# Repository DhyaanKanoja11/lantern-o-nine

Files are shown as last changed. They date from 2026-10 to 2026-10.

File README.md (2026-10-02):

# **Lantern-o-Nine**

A 9-key custom macropad built around the Seeed XIAO RP2040, featuring an EC11 rotary encoder for volume control, a 0.91" OLED display to show current status, and SK6812 RGB underglow. Housed in a custom 3D printed snap-fit case with a honeycomb vent rosette and debossed name!

Made as a submission to [Hack Club's Hackpad](https://hackpad.hackclub.com/) program.  
> *This is my first hardware project! Thank you Hack Club for this amazing opportunity!! <3*

---

<p align="center">
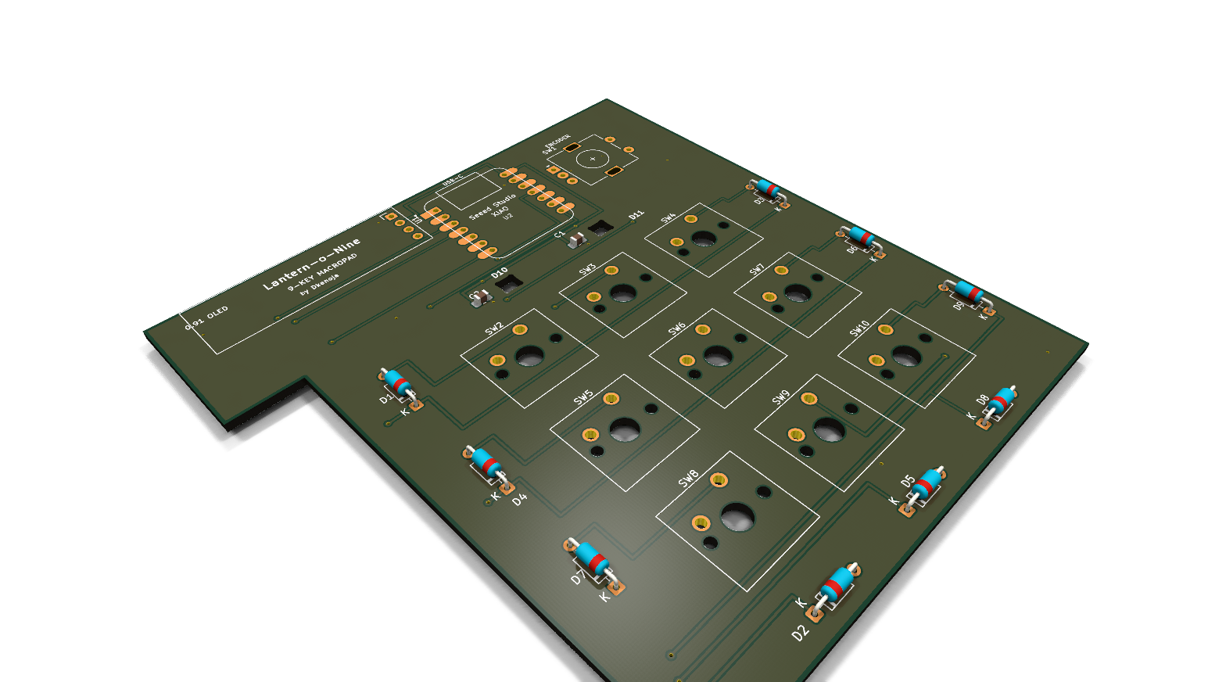
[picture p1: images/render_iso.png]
Lantern-o-Nine 3D Render
  
</p>

### Quick Links
- [View CAD Files](./CAD/)
- [View PCB Files](./PCB/)
- [View Firmware](./Firmware/)
- [View Production Files](./production/)

---

## Pictures & Design Files

### 3D PCB Renders
| Top View | Bottom View |
| :---: | :---: |
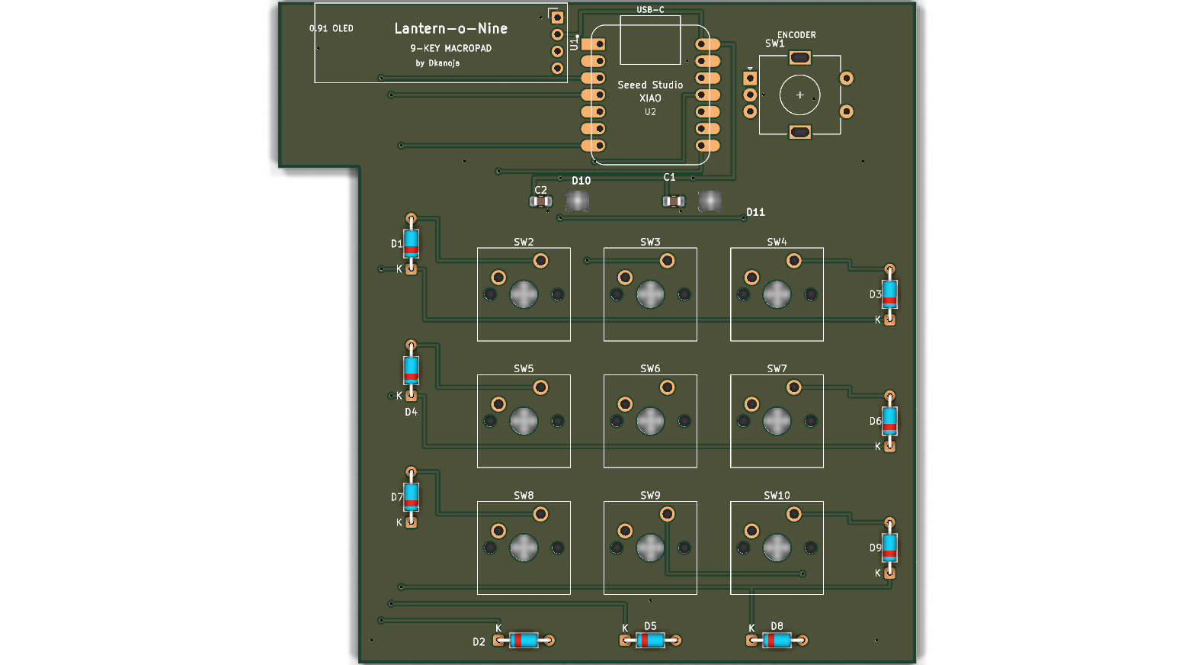
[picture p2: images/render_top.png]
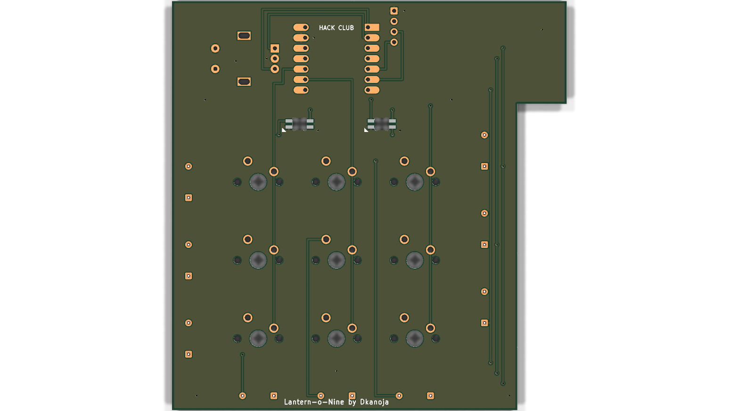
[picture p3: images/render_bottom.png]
|  |  |

### Schematic & PCB Routing
| Schematic Diagram | 2D PCB Layout |
| :---: | :---: |
|  |  |

### 3D CAD Enclosure & Mechanical Assembly
| Exploded Assembly (PCB Encasing) | Fully Assembled Case | Bottom Case (Rosette & Logo) |
| :---: | :---: | :---: |
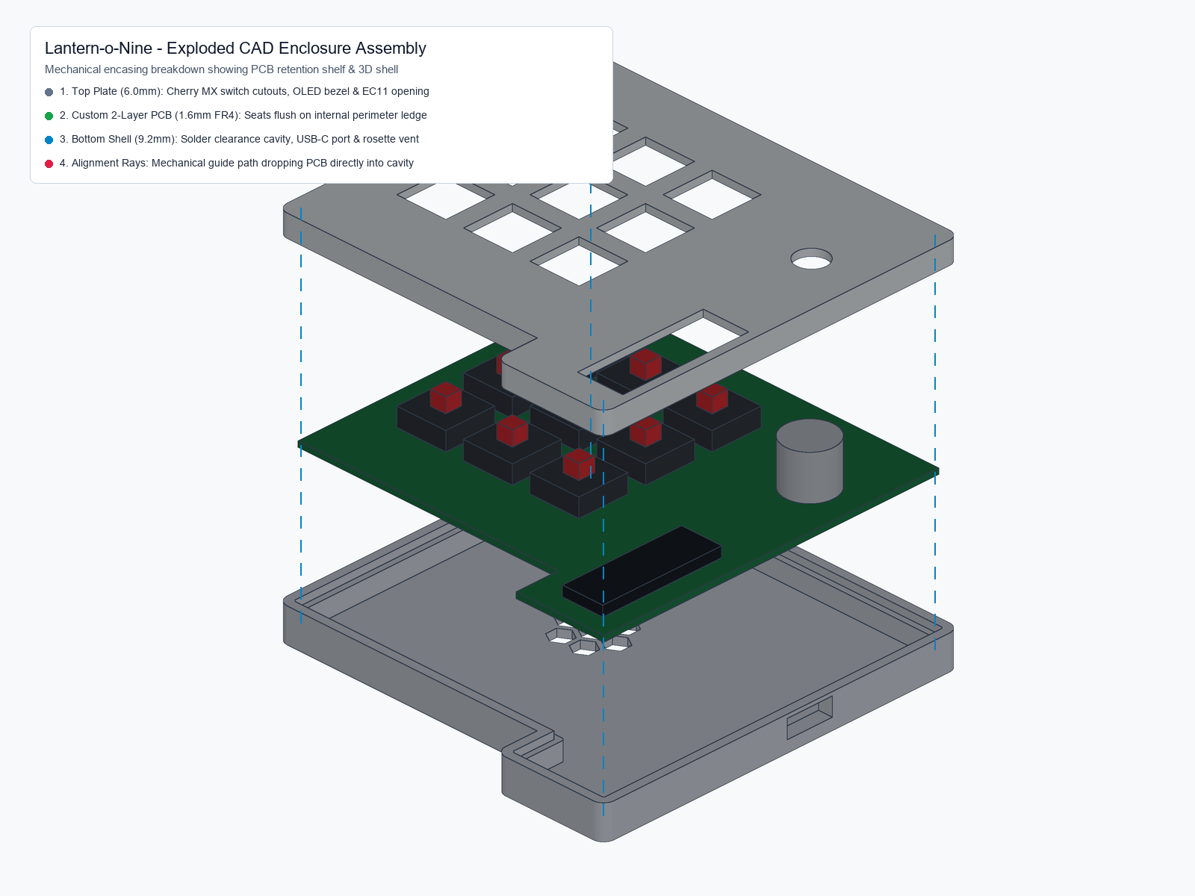
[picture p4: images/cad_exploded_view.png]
Exploded Assembly View
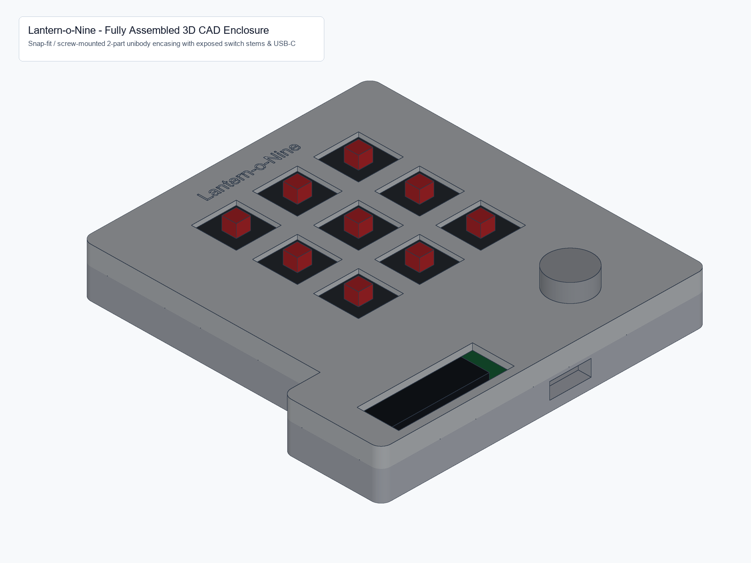
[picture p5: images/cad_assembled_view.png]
Fully Assembled CAD View
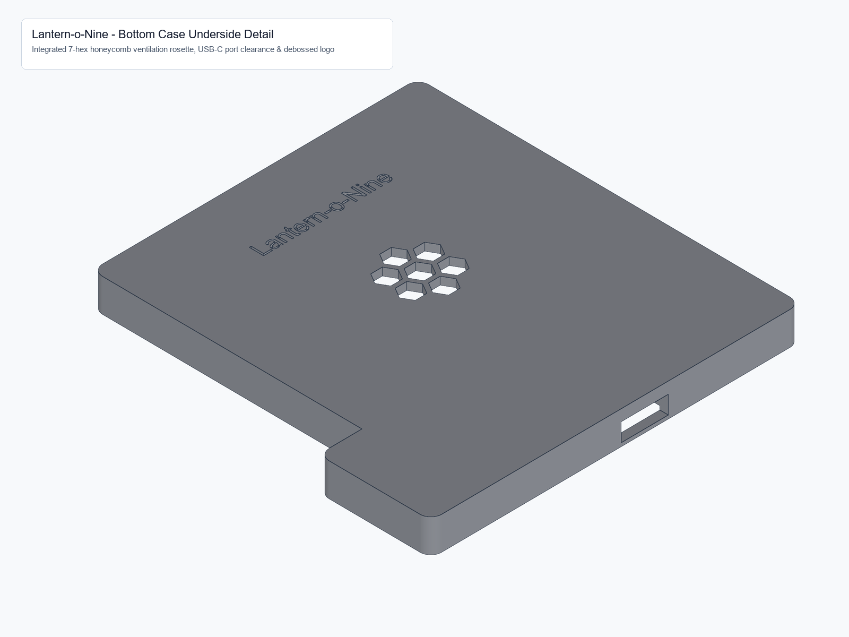
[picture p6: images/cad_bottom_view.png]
Bottom Case Detail View
|  |  |  |

The 2-piece enclosure consists of a 6.0mm top plate and 9.2mm bottom shell:
- **Mechanical Encasing:** The custom 2-layer PCB (1.6mm FR4) drops directly into the bottom shell, seating flush on an internal perimeter retention shelf with dedicated clearance below for diode and switch pin solder joints.
- **Top Plate Retention:** The top plate caps the assembly, clamping the PCB securely while exposing the 9 Cherry MX switch stems through 14x14mm cutouts, an OLED viewing bezel, and a rotary encoder shaft opening.
- **Thermal & Ports:** The underside features an integrated 7-hex honeycomb ventilation rosette and debossed "Lantern-o-Nine" branding, with an aligned rear cutout for the Seeed Xiao USB-C port.

---

## Features
- **9 Cherry MX Mechanical Switches** in a 3x3 matrix with 1N4148 diodes so there's zero ghosting (NKRO).
- **EC11 Rotary Encoder** to smoothly change volume up/down, plus click-to-mute.
- **0.91" 128x32 I2C OLED Display** showing the active layer and status.
- **2x SK6812MINI-E Reverse-Mount RGB LEDs** shining through cutouts in the PCB for nice underglow.
- **Custom 3D Printed Case** with a 2mm switch plate, recessed PCB mounting ledge, USB-C cutout, debossed "Lantern-o-Nine" logo, and a little honeycomb vent pattern on the bottom!

---

## Components Used (BOM)

All parts are beginner friendly and follow the Hack Club approved parts list:

- **Seeed Studio XIAO RP2040** (1x)
- **Cherry MX / Gateron switches** (9x)
- **1N4148 switching diodes (DO-35)** (9x)
- **EC11 rotary encoder with push button** (1x)
- **0.91 inch SSD1306 I2C OLED display (128x32)** (1x)
- **SK6812MINI-E reverse-mount addressable RGB LEDs** (2x)
- **0805 SMD 0.1uF decoupling capacitors** (2x)
- **3D printed top plate and bottom case** (Printed in PLA/PETG)

---

## Xiao RP2040 Pinout

| Pin | GPIO | What it connects to |
| :--- | :--- | :--- |
| **D0** | GPIO26 | Encoder Pin B |
| **D1** | GPIO27 | Encoder Pin A |
| **D2** | GPIO28 | Matrix Row 1 (Diodes D1, D2, D3) |
| **D3** | GPIO29 | Matrix Row 2 (Diodes D4, D5, D6) |
| **D4** | GPIO6  | OLED Display SDA (I2C) |
| **D5** | GPIO7  | OLED Display SCL (I2C) |
| **D6** | GPIO0  | Matrix Row 3 (Diodes D7, D8, D9) |
| **D7** | GPIO1  | Matrix Column 1 (Switches SW2, SW5, SW8) |
| **D8** | GPIO2  | Matrix Column 2 (Switches SW3, SW6, SW9) |
| **D9** | GPIO4  | Matrix Column 3 (Switches SW4, SW7, SW10) |
| **D10**| GPIO3  | RGB LED Data Line (DIN) |
| **3V3**| 3.3V | Power to OLED Display |
| **5V** | 5.0V | Power to SK6812 RGB LEDs |
| **GND**| GND | Ground Plane |

---

## Firmware (CircuitPython + KMK)

The firmware is super simple and runs using [KMK](https://github.com/KMKfw/kmk_firmware) on CircuitPython.

### How to set it up:
1. Hold the `BOOT` button on the Xiao RP2040 while plugging it into your computer with a USB-C cable.
2. Drag and drop the CircuitPython `.uf2` file for Xiao RP2040 from [circuitpython.org](https://circuitpython.org/board/seeed_xiao_rp2040/).
3. Once the drive reboots as `CIRCUITPY`, download [KMK Firmware](https://github.com/KMKfw/kmk_firmware) and copy the `kmk/` folder into the `CIRCUITPY` drive.
4. Copy [`Firmware/main.py`](./Firmware/main.py) into the `CIRCUITPY` drive and rename it to `code.py`.

### 3-Mode Layout:
- **Top Row (Mode Switchers):** Key 1 = Spotify Mode | Key 2 = Git Mode | Key 3 = Code Mode
- **Mode 1 (Spotify):** Prev Track, Play/Pause, Next Track, Vol Down, Mute, Vol Up
- **Mode 2 (Git):** `git status`, `git add .`, `git commit`, `git push`, Toggle Terminal (`Ctrl+~`), Clear (`Ctrl+L`)
- **Mode 3 (Code):** Copy (`Ctrl+C`), Paste (`Ctrl+V`), Cut (`Ctrl+X`), Undo (`Ctrl+Z`), Redo (`Ctrl+Y`), Format (`Shift+Alt+F`)
- **Rotary Knob:** Turn clockwise for Volume Up, counter-clockwise for Volume Down.

---

## Repository Structure

```text
lantern-o-nine/
├── README.md                 # This file!
├── .gitignore                # KiCad gitignore
├── CAD/
│   ├── assembled-model.STEP  # Full 3D assembly of case + PCB
│   ├── Top.STEP              # Switch plate CAD model
│   └── Bottom.STEP           # Bottom enclosure CAD model
├── PCB/
│   ├── hackpadtrial.kicad_pro# KiCad 10 project file
│   ├── hackpadtrial.kicad_sch# Schematic
│   ├── hackpadtrial.kicad_pcb# PCB Layout (96mm x 99.5mm, 2-layer, 0 DRC errors)
│   └── hackpadtrial.kicad_prl# KiCad settings
├── Firmware/
│   └── main.py               # CircuitPython & KMK keyboard code
├── production/
│   ├── gerbers.zip           # Gerbers and drill files for JLCPCB
│   ├── Top.STEP              # Switch plate 3D file
│   ├── Bottom.STEP           # Bottom case 3D file
│   └── main.py               # Production firmware copy
└── images/
    ├── render_iso.png
    ├── render_top.png
    ├── render_bottom.png
    ├── cad_exploded_view.png # Exploded view showing PCB encasing
    ├── cad_assembled_view.png# Fully assembled 3D case
    ├── cad_bottom_view.png   # Bottom shell with honeycomb & logo
    ├── schematic.svg
    └── pcb_layout.svg
```

---

## AI Declaration

AI tools (Antigravity CLI and ChatGPT) were used as educational mentors and engineering copilots throughout this build:
- **Mentorship & Tooling:** Learning new software workflows across KiCad 10, design rules, and CAD export standards.
- **Firmware Architecture:** Advice and guidance on structuring the 3-mode KMK keymap, matrix scanning, and CircuitPython extensions.
- **Documentation:** Assistance reviewing and structuring the README and project devlogs.

All circuit schematics, board routing, mechanical 3D tolerances, and component choices were designed and tested by me.

---

## Credits

Built by **Dhyaan Kanoja** ([@DhyaanKanoja11](https://github.com/DhyaanKanoja11)).  
Special thanks to **Atulya** ([@Person-0](https://github.com/Person-0)) for help and inspiration from his awesome [Spicofy](https://github.com/Person-0/spicofy) project!  
Huge shoutout to the **Hack Club** team and everyone on the Slack helping high schoolers build real hardware! <3

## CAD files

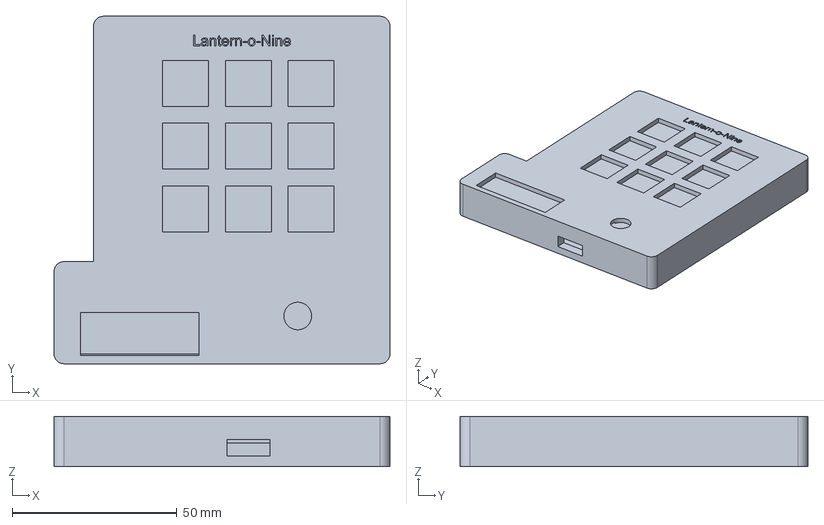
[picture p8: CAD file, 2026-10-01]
CAD/assembled-model.STEP
102.0 x 105.5 x 15.2 mm

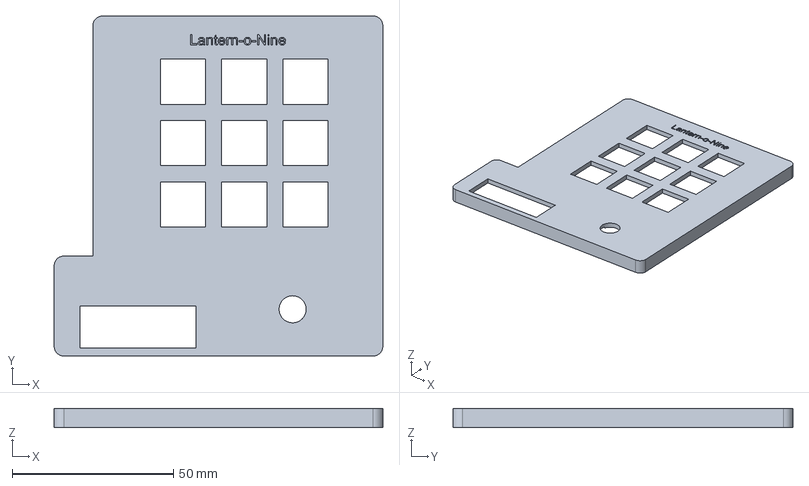
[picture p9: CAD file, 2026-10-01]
production/Top.STEP
102.0 x 105.5 x 6.00 mm

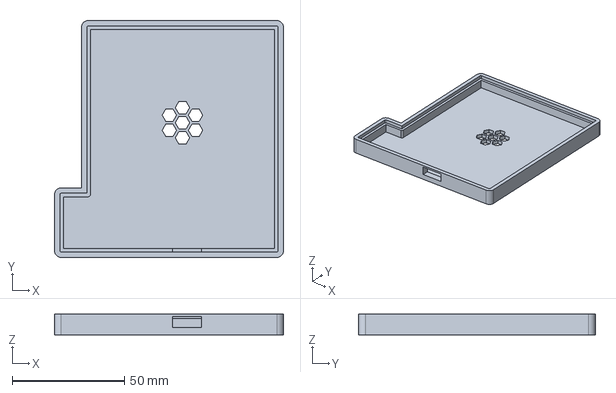
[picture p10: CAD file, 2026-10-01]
production/Bottom.STEP
102.0 x 105.5 x 9.20 mm

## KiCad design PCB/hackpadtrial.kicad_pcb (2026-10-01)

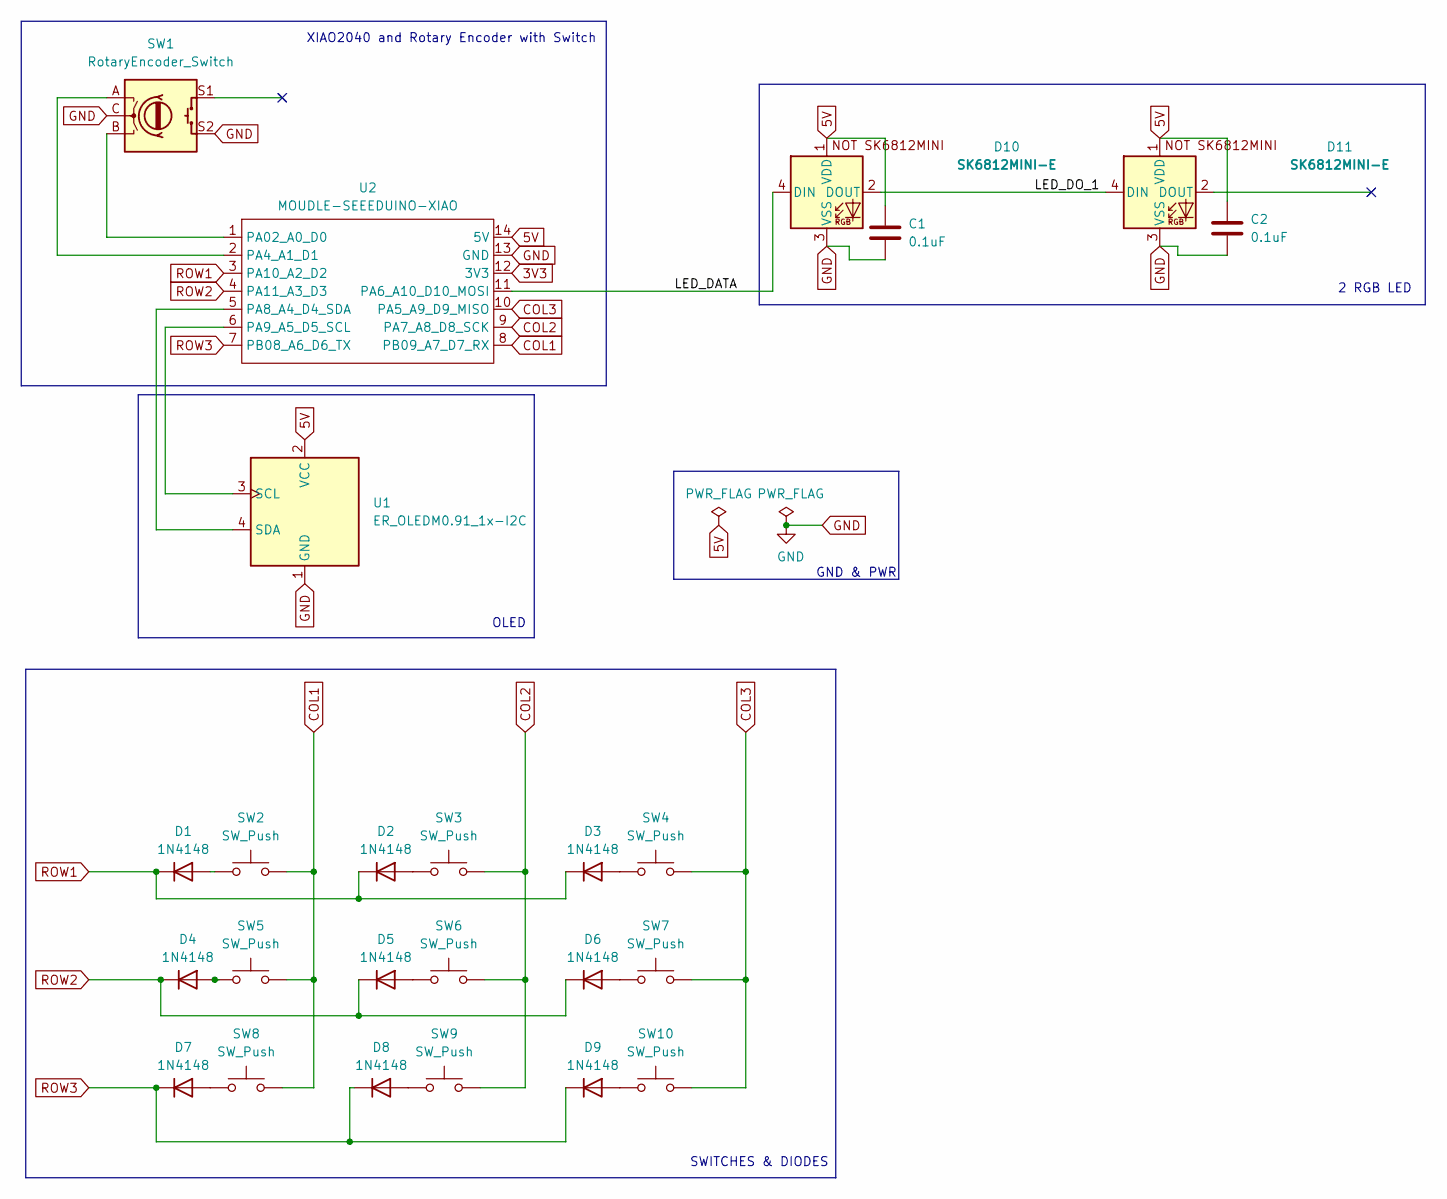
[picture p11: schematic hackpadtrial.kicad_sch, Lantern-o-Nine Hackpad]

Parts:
C1, C2: 0.1uF; C_0805_2012Metric_Pad1.18x1.45mm_HandSolder
D1, D2, D3, D4, D5, D6, D7, D8, D9: 1N4148; D_DO-35_SOD27_P7.62mm_Horizontal
D10, D11: SK6812MINI-E; SK6812MINI-E_fixed
SW1: RotaryEncoder_Switch; RotaryEncoder_Alps_EC11E-Switch_Vertical_H20mm
SW2, SW3, SW4, SW5, SW6, SW7, SW8, SW9, SW10: SW_Push; SW_Cherry_MX_1.00u_PCB
U1: ER_OLEDM0.91_1x-I2C
U2: MOUDLE-SEEEDUINO-XIAO; XIAO-Generic-Hybrid-14P-2.54-21X17.8MM

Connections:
3V3: U2.12 (3V3)
5V: C1.1, C2.1, D10.1 (VDD), D11.1 (VDD), U1.2 (VCC), U2.14 (5V)
/LED_DATA: D10.4 (DIN), U2.11 (PA6_A10_D10_MOSI)
/LED_DO_1: D10.2 (DOUT), D11.4 (DIN)
COL1: SW2.2, SW5.2, SW8.2, U2.8 (PB09_A7_D7_RX)
COL2: SW3.2, SW6.2, SW9.2, U2.9 (PA7_A8_D8_SCK)
COL3: SW4.2, SW7.2, SW10.2, U2.10 (PA5_A9_D9_MISO)
GND: C1.2, C2.2, D10.3 (VSS), D11.3 (VSS), SW1.C, SW1.S2, U1.1 (GND), U2.13 (GND)
unnamed: D1.2 (A), SW2.1
unnamed: D2.2 (A), SW3.1
unnamed: D3.2 (A), SW4.1
unnamed: D4.2 (A), SW5.1
unnamed: D5.2 (A), SW6.1
unnamed: D6.2 (A), SW7.1
unnamed: D7.2 (A), SW8.1
unnamed: D8.2 (A), SW9.1
unnamed: D9.2 (A), SW10.1
unnamed: U1.3 (SCL), U2.6 (PA9_A5_D5_SCL)
unnamed: U1.4 (SDA), U2.5 (PA8_A4_D4_SDA)
unnamed: SW1.B, U2.1 (PA02_A0_D0)
unnamed: SW1.A, U2.2 (PA4_A1_D1)
ROW1: D1.1 (K), D2.1 (K), D3.1 (K), U2.3 (PA10_A2_D2)
ROW2: D4.1 (K), D5.1 (K), D6.1 (K), U2.4 (PA11_A3_D3)
ROW3: D7.1 (K), D8.1 (K), D9.1 (K), U2.7 (PB08_A6_D6_TX)

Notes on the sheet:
2 RGB LED
GND & PWR
SWITCHES & DIODES
OLED
XIAO2040 and Rotary Encoder with Switch

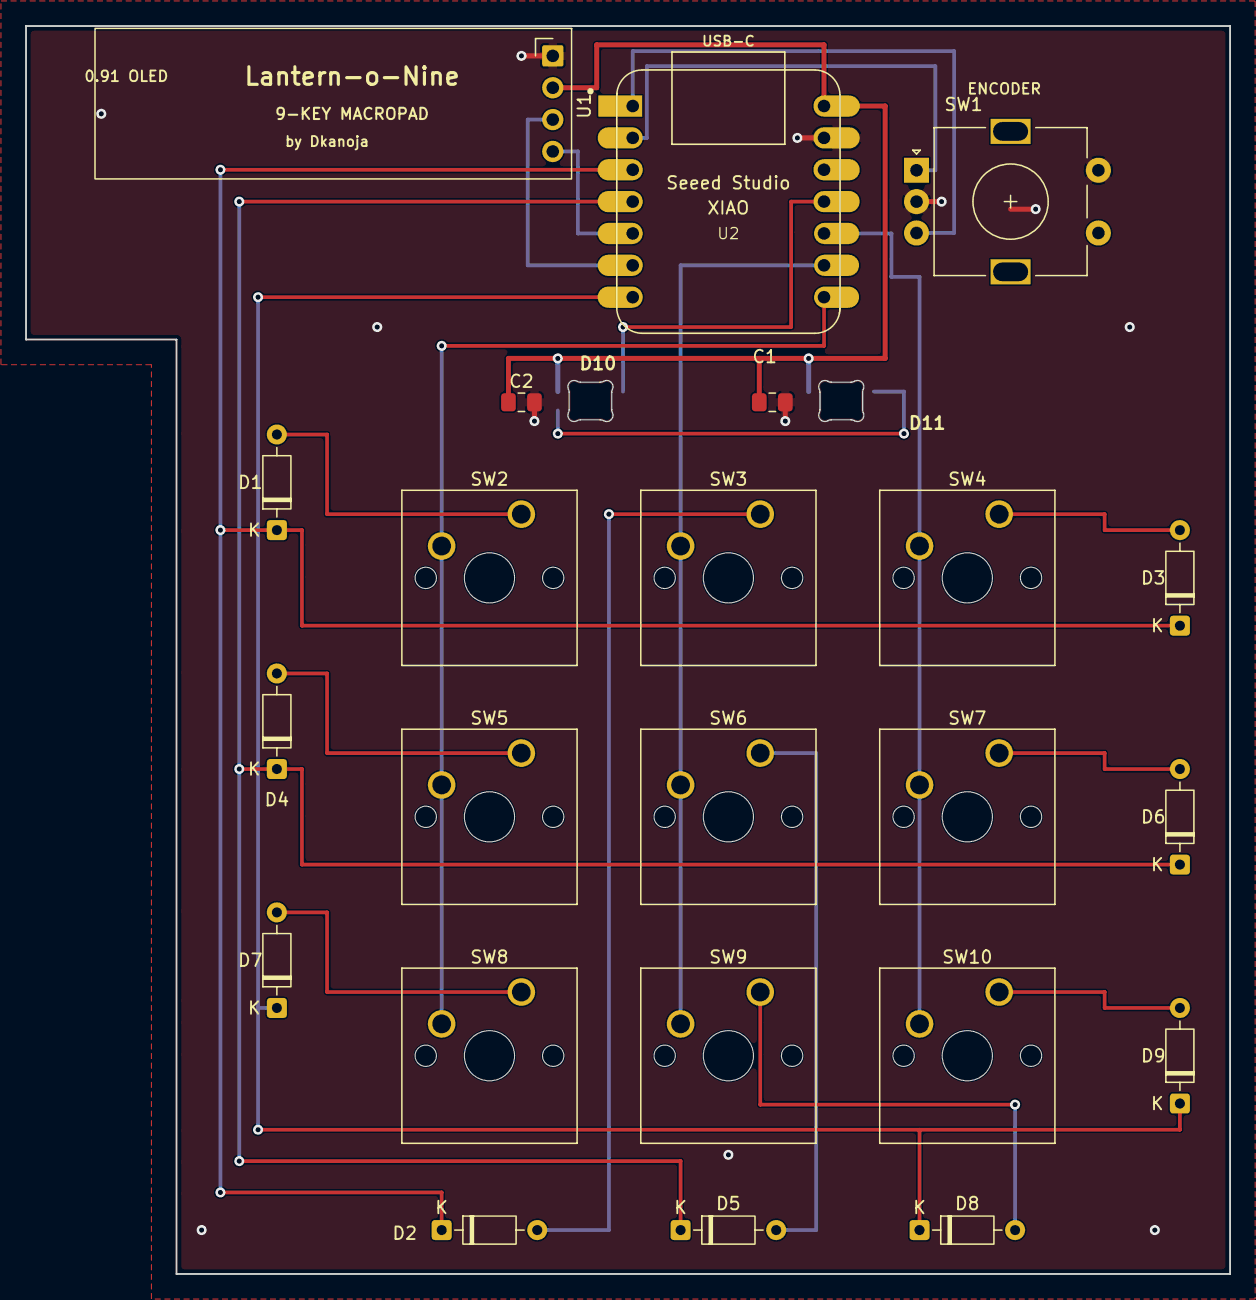
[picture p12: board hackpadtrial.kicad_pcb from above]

Board: 2 copper layers, 96.0 x 99.5 mm, 25 parts (0 on the bottom side), 23 nets.

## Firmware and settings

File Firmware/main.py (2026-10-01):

# Lantern-o-Nine 9-Key Macropad Firmware
# Created by Dhyaan Kanoja (@DhyaanKanoja11) for Hack Club Hackpad
# Running CircuitPython with KMK Firmware on Seeed Studio XIAO RP2040

import board

from kmk.kmk_keyboard import KMKKeyboard
from kmk.keys import KC
from kmk.scanners import DiodeOrientation
from kmk.modules.layers import Layers
from kmk.modules.encoder import EncoderHandler
from kmk.handlers.sequences import send_string, simple_key_sequence
from kmk.extensions.peg_oled_display import Oled, OledDisplayMode, OledReactionType
from kmk.extensions.RGB import RGB

keyboard = KMKKeyboard()

# -----------------------------------------------------------------------------
# 1. 3x3 SWITCH MATRIX PINOUT (Seeed Xiao RP2040)
# -----------------------------------------------------------------------------
keyboard.row_pins = (board.D2, board.D3, board.D6)
keyboard.col_pins = (board.D7, board.D8, board.D9)
keyboard.diode_orientation = DiodeOrientation.ROW2COL

# -----------------------------------------------------------------------------
# 2. MODULES & EXTENSIONS
# -----------------------------------------------------------------------------
# Multi-layer support
keyboard.modules.append(Layers())

# Rotary encoder (EC11)
encoder_handler = EncoderHandler()
encoder_handler.pins = ((board.D1, board.D0, None, False),)
encoder_handler.map = [((KC.VOLD, KC.VOLU),)]
keyboard.modules.append(encoder_handler)

# 0.91" 128x32 I2C OLED display (SSD1306)
oled_ext = Oled(
    OledDisplayMode.LAYER,
    oWidth=128,
    oHeight=32,
    reaction_type=OledReactionType.STATIC,
)
keyboard.extensions.append(oled_ext)

# RGB underglow (2x SK6812MINI-E on D10)
rgb = RGB(pixel_pin=board.D10, num_pixels=2)
keyboard.extensions.append(rgb)

# -----------------------------------------------------------------------------
# 3. 3-MODE KEYMAP CONFIGURATION
# -----------------------------------------------------------------------------
# Top Row: Mode switchers (Row 1 is identical across all layers)
#   - Key 1: Mode 1 (Spotify / Media)
#   - Key 2: Mode 2 (Git / Terminal)
#   - Key 3: Mode 3 (Code / IDE)

MODE_SPOTIFY = KC.TO(0)
MODE_GIT     = KC.TO(1)
MODE_CODE    = KC.TO(2)

keyboard.keymap = [
    # Layer 0: Spotify / Media Mode
    [
        MODE_SPOTIFY,   MODE_GIT,        MODE_CODE,
        KC.MPRV,        KC.MPLY,         KC.MNXT,
        KC.VOLD,        KC.MUTE,         KC.VOLU,
    ],
    # Layer 1: Git & Terminal Mode
    [
        MODE_SPOTIFY,   MODE_GIT,        MODE_CODE,
        simple_key_sequence((send_string("git status\n"),)),
        simple_key_sequence((send_string("git add .\n"),)),
        simple_key_sequence((send_string("git commit -m 'update'\n"),)),
        simple_key_sequence((send_string("git push\n"),)),
        KC.LCTL(KC.GRAVE),  # Toggle VS Code terminal
        KC.LCTL(KC.L),      # Clear screen
    ],
    # Layer 2: Code & Editing Mode
    [
        MODE_SPOTIFY,   MODE_GIT,        MODE_CODE,
        KC.LCTL(KC.C),  KC.LCTL(KC.V),   KC.LCTL(KC.X),
        KC.LCTL(KC.Z),  KC.LCTL(KC.Y),   KC.LSFT(KC.LALT(KC.F)),  # Format doc
    ],
]

if __name__ == '__main__':
    keyboard.go()

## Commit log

2026-10-01 feat: Lantern-o-Nine 9-key macropad submission
    [Bottom.STEP, Top.STEP, assembled-model.STEP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]
2026-10-02 cad images added
2026-10-02 Update CAD enclosure renders and README
